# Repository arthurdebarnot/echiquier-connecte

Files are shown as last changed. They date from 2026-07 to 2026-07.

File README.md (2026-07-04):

# Echiquier connecté

## Installation des packages

`conda env create -f environment-windows.yml`

Il est nécessaire d'avoir l'exécutable `stockfish-windows-x86-64-avx2.exe` dans un dossier nommé `stockfish` pour que le programme fonctionne. Ce fichier peut être téléchargé au lien suivant : [télécharger stockfish 18](https://github.com/official-stockfish/Stockfish/releases/latest/download/stockfish-windows-x86-64-avx2.zip) (décompressez le fichier et placez le fichier stockfish dans le même dossier que les autres fichiers Python)

## Utilité de chaque fichier

- [main.py](./main.py) : contient la boucle de jeu : à chaque étape, calcule si un coup a été joué
- [magnetboard.py](./magnetboard.py) : définit la classe MagnetBoard qui permet de contenir l'état des reed switches mais aussi d'autres informations complémentaires importantes à stocker d'un tick à l'autre comme par exemple le fait qu'un roque est en train d'être fait
- [chesswindow.py](./chesswindow.py) : définit la classe ChessWindow qui permet de stocker la GUI et notamment ses différents éléments pour ensuite pouvoir les mettre à jour au fil des ticks
- [board_logic.py](./board_logic.py) : gère la compréhension de ce qui se passe sur le magnetBoard, comprend lorsqu'un coup est joué en fonction des reeds switches qui sont activés ou désactivés
- [evaluation.py](./evaluation.py) : contient les fonctions permettant de demander à Stockfish d'évaluer un coup
- [stockfish_interface.py](./stockfish_interface.py) : programme permettant de faire l'interface avec Stockfish et d'intéragir avec l'engine.
- [reedswitches-leds.py](./reedswitches-leds.py) : programme tournant sur la Raspberry Pi permettant d'allumer en vert les cases avec une pièces dessus. Nécessite l'installation des packages de [environment-rpi.yml](./environment-rpi.yml).

## Fonctionnement du programme

### Cas de simulation sans le raspberry

Etant donné que nous n'avons pas eu accès aux capteurs nous avons beaucoup développé l'aspect simulation des inputs pour tester notre programme d'échecs.

Le fichier à exécuter est celui qui s'appelle [main.py](./main.py). Il est possible de modifier le FEN de départ. Une interface graphique s'ouvre et permet de visualiser la position des capteurs allumés, ainsi que la position des pièces enregistrée par l'ordinateur.

En cliquant sur les cases, on peut simuler l'allumage ou l'extinction d'un reed switch. Lorsque le programme détecte qu'un coup a été effectué (par exemple, soulèvement du pion en e2, puis posage sur pion en e4), il met à jour son échiquier interne et déplace la lettre du pion.

Le programme prend en charge le roque, la prise en passant, la promotion ainsi que les différentes façon de terminer la partie : échec et mat, pat, insuffisance de matériel, nulle par répétition, nulle par suite consécutive de 50 coups sans prise ni déplacement de pion.

#### Promotion

Lorsqu'un pion arrive sur la case de promotion, il faut le changer en une autre pièce. Pour indiquer quelle pièce on a choisi à l'ordinateur, nous avons décidé de demander au joueur de modifier l'état d'une case tampon.

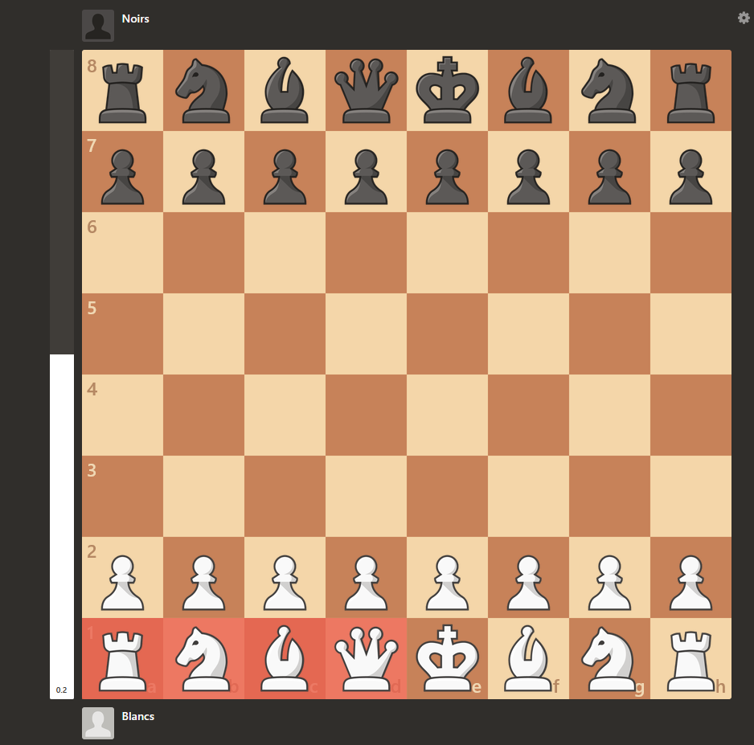
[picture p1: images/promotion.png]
image des cases tampons


Si une pièce est posée sur la case tampon, la pièce doit être soulevée puis reposée. Si aucune pièce n'est sur la case tampon, une pièce doit être posée puis reprise.

---

**ATTENTION**
Il faut bien penser que quand le pion est promu, il doit être remplacé par une autre pièce, et donc pour que l'ordinateur valide la promotion, la case du pion doit être désactivée puis réactivée pour simuler ce changement de pièce.

---

#### Choix du FEN de départ

Il est possible de changer la position de départ en le précisant à l'aide d'un FEN. Il est possible de trouver le FEN d'une position à l'aide de ce [lien](https://www.chess.com/analysis)

#### Evaluation par stockfish des coups

L'intérêt de cet échiquier connecté est de pouvoir évaluer chaque coup et donner du "feedback" en temps réel aux jouers. Ceci se fait à travers un algorithme d'échecs, Stockfish. À chaque coup, l'état du jeu (représenté par le FEN) est envoyé à Stockfish, qui évalue la situation et renvoie une valeur (qu'on passe ensuite dans la fonction $\mathrm{argsinh}$ pour donner plus de valeur à des modification d'évaluation proche de 0). En le comparant avec la situation d'avant, on peut ainsi juger la pertinence du coup.

## Partie électronique

### LED strip

Pour mieux communiquer des information importantes (coup illégal, "blunder", etc.) aux joueurs, une LED strip est mise sous l'échiquier et peut allumer chaque case de différentes couleurs (rouge, vert, orange, etc.). 

### Reed switch

Pour détecter la présence ou non d'une pièce, des reed switches sont mis sous chaque case et des aimants sont mis sous chaque pièce. Ainsi, lorsqu'une pièce est mise sur une case, le reed switch s'active et un courant circule. 

La lecture se fait grâce à [reedswitches-leds.py](./reedswitches-leds.py)

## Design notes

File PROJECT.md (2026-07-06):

## Echiquier Physique

### Pièces

Bien que de nombreux modèles de pièces d'échecs existent sur internet, nous avons préféré créer nos modèles nous même afin d'avoir un jeu adapter à la taille de nos cases et à celles des aimants que nous esperions recevoir. Du fait de l'absence des aimants, nous avons dû utiliser celle du projet IDS de cette année.

### Structure du plateau

Afin d'éviter que la LED d'une case n'en éclaire une autre, nous avons décidé de réaliser une grille coupant chaque cases de ses voisines. Seul un cercle bas dans le plateau permet aux cases de communiquer pour faire passer le ruban LED. 

La Grille a été réalisé grâce à la découpeuse laser, dont la précision permet un emboitement sans trop de jeu. Il y a un carré pour le bas. Chacune des 18 barres qui composent la grille sont tenus par 4 points à la plaque.

Le haut du plateau est une impression bicolore blanc-noir de 0.5mm, permettant de faire passer la lumière des LEDS. L'utilisation de PETG translucide pour mieux faire passer la lumière a été écarté sous les conseils de Némo.

### Capteurs

En l'absence de capteurs reçus, nous avons récupéré le montage du trimestre IDS de cette année. Nous n'avons donc pas pu réellement modifier cette structure et avons donc plutôt adapter le reste du plateau à celle-ci. 

ll aurait fallut faire usage d'un multiplexeur pour permettre de sonder toutes les cases malgré le nombre d'inputs limité du Raspberry Pi. En l'absence de celui-ci, nous n'avons accès qu'à 48 cases (8 colonnes et seulement 6 lignes). La strucutre récupéré a posé pas mal de problèmes (capteurs cassés, nécessité de resouder plusieurs connexions, etc.).

## Partie informatique

### Mission principale

Nous avons choisi d'utiliser le package python `chess.py` pour gérer ce qui révèle de la logique du jeu d'échecs en lui-même : légalité des coups, possibilité de réaliser une roque, etc. Notre défi était de donner, à partir des données des capteurs, les bonnes informations à `chess.py`. 

En effet, les capteurs nous indiquent seulement si il y a ou non une pièce sur une certaine case, mais n'en disent rien sur la nature de la pièce (que ce soit son rang ou son couleur). Il fallait ainsi construire une logique qui permet de passer de la "magnet-board" (grille de 1 et des 0 indiquant la présence ou non d'une pièce) à des coups compréhensibles par `chess.py`.

### Organisation du code

On a d'abord fait un prototype de code pour commencer réflechir à la structure du code. Cependant, il est vite devenu incompréhensible, et il fallait qu'on refasse tout de scratch pour avoir une architecture cohérente et robuste.

### Difficultés recontrées

Avoir une architecture de code cohérente et lisible était plus dur que prévu, il fallait réflechir en avance de comment on voulait structurer la logique et les interactions entre les différentes parties du code. 

Par ailleurs, la gestion des coups illégaux était un peu délicat : en effet, si `chess.py` détecte un mauvais coup, il réfuse de l'enregistrer. Mais physiquement parlant, la pièce a quand-même été déplacée, et il faut qu'on "dise au code" qu'il est "légal" de rebouger la pièce pour la remettre dans son position initial.

Une grande défi à surmonter était la gestion de la roque : de la point de vue du "magnet-board", c'est une situation très bizarre, puisqu'il voit 2 pièces de la même couleur soulevées, ce qui est normalement illégal. Il faut alors réussir à bien détecter ce qui se passe et basculer sur une autre système de gestion pour bien comprendre et enregistrer ce qui se passe sur l'échiquier.

## Lien physique - informatique

Malheureusement, en raison des difficultés du côté physique avec les capteurs, on n'a pas pu connecter les deux parties de notre projet. Avec un peu plus de temps, et surtout le matériel nécessaire, on aurait aimé faire le lien et compléter le projet.

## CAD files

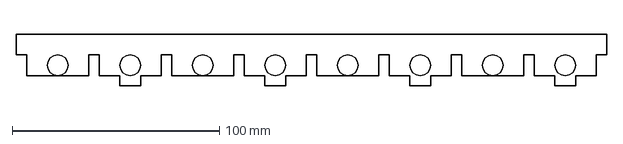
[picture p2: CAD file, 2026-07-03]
Echiquier physique/Fichiers Découpe-Laser/barre1.dxf
285.0 x 25.0 mm

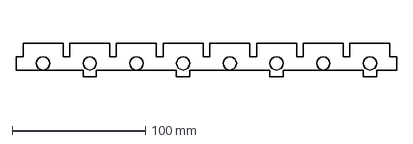
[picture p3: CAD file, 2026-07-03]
Echiquier physique/Fichiers Découpe-Laser/barre2.dxf
285.0 x 25.0 mm

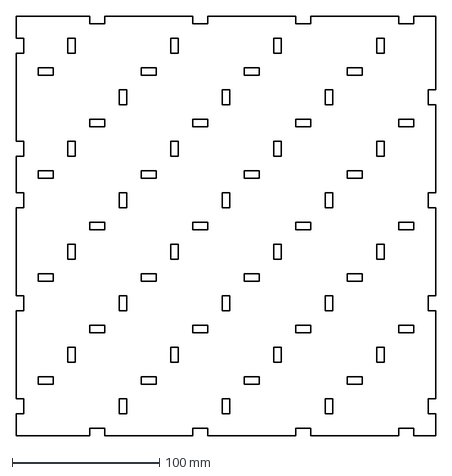
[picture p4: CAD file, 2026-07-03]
Echiquier physique/Fichiers Découpe-Laser/chees_bas.dxf
285.0 x 285.0 mm

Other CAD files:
Echiquier physique/Modèles 3D/barre-échecs.f3d
Echiquier physique/Modèles 3D/cavalier.f3d
Echiquier physique/Modèles 3D/echiquier bas.f3d
Echiquier physique/Modèles 3D/fou.f3d
Echiquier physique/Modèles 3D/pion.f3d
Echiquier physique/Modèles 3D/roi.f3d
Echiquier physique/Modèles 3D/échiquier.f3z

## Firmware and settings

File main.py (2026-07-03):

import chess
from board_logic import gameTick
from magnetboard import MagnetBoard
import evaluation as evaluation
from chesswindow import ChessWindow

fen = chess.STARTING_FEN # sélection du fen de la position de départ
prev_fen = fen # stocke le FEN de la dernière position

chessBoard = chess.Board(fen) # plateau d'échec de l'ordinateur
magnetBoard = MagnetBoard(chessBoard) # plateau magnétique se mettant à jour en fonction des reed switches
chessWindow = ChessWindow(magnetBoard, chessBoard) # fenêtre graphique

prev_value = evaluation.evaluate(chessBoard.fen()) # évaluation de la dernière position


while True:
    gameTick(magnetBoard, chessBoard, chessWindow) # collecte les nouveaux états des reed switches et met à jour le magnetBoard et le chessBoard si besoin. Mets aussi à jour la gui

    # Vérification des conditions de fin de partie

    if chessBoard.is_checkmate():
        print("Fin de partie par échec et mat !")
        break
    if chessBoard.is_stalemate():
        print("Fin de partie par pat !")
        break
    if chessBoard.is_insufficient_material():
        print("Fin de partie par manque de matériel !")
        break
    if chessBoard.can_claim_draw():
        print("La nulle peut être réclamée !")
        break

    prev_fen, prev_value = evaluation.judge_move(chessBoard, prev_fen, prev_value) # mise à jour de la dernière évaluation et du dernier fen

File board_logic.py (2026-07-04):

## Code pour gérer la plateau de jeu: quelles pièces sont où, etc.
import numpy as np
import chess
import time
from magnetboard import MagnetBoard
from chesswindow import ChessWindow

# Game Loop
def gameTick(magnetBoard: MagnetBoard, chessBoard: chess.Board, chessWindow: ChessWindow):
    """Effectue toutes les actions pour détecter de potentiels nouveaux coups joués"""

    previous_magnetBoard = magnetBoard.board.copy() # copie du dernier état du magnetBoard

    magnetBoard.update(chessBoard, chessWindow) # collecte de l'état des reed switches

    move = None

    if magnetBoard.is_invalid: # cas où un coup invalide aurait été joué et qu'on attend que le plateau revienne dans la dernière position valide
        if np.array_equal(magnetBoard.board, magnetBoard.last_valid_board):
            if magnetBoard.validation_start_time < 0:
                magnetBoard.validation_start_time = time.time() # premier instant où le plateau est revenu dans une position valide
            elif time.time() - magnetBoard.validation_start_time >= 2: # si le plateau est dans la dernière posiiton valide depuis plus de 2 secondes, on reprend le fonctionnement normal
                magnetBoard.is_invalid = False
                magnetBoard.validation_start_time = -1
                magnetBoard.friendly_piece_up_square = None
                magnetBoard.opponent_piece_up_square = None
                magnetBoard.is_castling = None
                magnetBoard.castling_rook_squares = None
                magnetBoard.is_promoting = False
                magnetBoard.promoting_piece_type = None
                magnetBoard.is_promotion_done = False
                magnetBoard.current_move = None
                print("La partie peut continuer !")
        else: # si on n'est pas dans la dernière position valide, on attend
            magnetBoard.validation_start_time = -1
        return

    if np.array_equal(magnetBoard.board, previous_magnetBoard): # s'il n'y a eu aucun changement sur le plateau on ne fait rien
        return
    
    # on détecte les différences entre l'état précédents et le nouvel état

    difference_magnetBoard = magnetBoard.board - previous_magnetBoard 
    difference_magnetBoard_nonzero = difference_magnetBoard.nonzero()

    if len(difference_magnetBoard_nonzero[0]) > 1: # si il y a plus d'une modification, on ne peut rien interpréter donc on rentre dans un cas invalide
        print("[INVALIDE] plusieurs pièces bougées en même temps")
        magnetBoard.is_invalid = True
        return
    
    modified_square = chess.square(difference_magnetBoard_nonzero[1][0], difference_magnetBoard_nonzero[0][0]) # on stocke la case modifiée

    if magnetBoard.is_promoting: # si une promotion est en cours
        tampon_squares = [chess.square(i, 7*(1 - chessBoard.turn)) for i in range(4)]

        if modified_square == magnetBoard.current_move.to_square: # la case du pion promu est en jeu
            if difference_magnetBoard[difference_magnetBoard_nonzero][0] == -1: # pion soulevé
                return
            else: # pion posé
                magnetBoard.is_promotion_done = True # variable qui retient si le pion a bien été promu en une autre pièce sur l'échiquier physique
        elif modified_square not in tampon_squares: # on touche à une case random pendant la promotion
            print("[INVALIDE] Tu ne peux pas modifier l'état d'une case random pendant la promotion")
            magnetBoard.is_invalid = True
            return
        else: # on modifie l'état d'une des 4 cases tampon
            if magnetBoard.friendly_piece_up_square is not None and magnetBoard.friendly_piece_up_square != modified_square:
                print("[INVALIDE] Tu as déjà touché une autre pièce")
                magnetBoard.is_invalid = True
                return

            magnetBoard.friendly_piece_up_square = modified_square # on stocke la case tampon modifiée, aucun rapport avec friendly ou que la pièce soit soulevée ou posée
            
            if magnetBoard.board[difference_magnetBoard_nonzero] != magnetBoard.last_valid_board[difference_magnetBoard_nonzero]: # tant qu'on n'est pas revenu dans l'état initial de la case tampon, on ne fait rien
                return
            
            # on est revenu à un état normal

            magnetBoard.promoting_piece_type = chess.Board(chess.STARTING_FEN).piece_at(modified_square).piece_type # on regarde alors la pièce qui correspond à la case tampon

        if not magnetBoard.is_promotion_done or magnetBoard.promoting_piece_type is None: # si la promotion n'est pas effectuée ou que la pièce n'est pas sélectionnée, on ne fait rien
            return
            
        magnetBoard.current_move.promotion = magnetBoard.promoting_piece_type # on modifie le coup à applique pour indiquer que c'est une promotion en la pièce choisie

        chessBoard.push(magnetBoard.current_move) # on ajoute le coup au chessBoard
        magnetBoard.last_valid_board = magnetBoard.board.copy() # on modifie le dernier magnetBoard valide

        magnetBoard.friendly_piece_up_square = None
        magnetBoard.is_promoting = False
        magnetBoard.is_promotion_done = False
        magnetBoard.current_move = None
        magnetBoard.promoting_piece_type = None
        return
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

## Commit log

2026-06-29 Added script for managing the board
2026-06-29 création fichier test simulation d'entrées du raspberry
2026-06-29 updated board logic
2026-06-29 updated board logic: end of day 29/06/26
2026-06-30 Stockfish lancé une seule fois pour toute la partie
2026-06-30 fixed bugs and added interface
    [board_logic.py]
2026-06-30 Added main script and changed architecture of board_logic.py
2026-06-30 evaluation stockfish and fix board_logic bug
    [board_logic.py, main.py]
2026-06-30 board logic
2026-07-02 Fin de partie
2026-07-02 bug fixed in evaluation.py
    [evaluation.py, main.py]
2026-07-03 ajustement pour la prise en passant
2026-07-03 annotation de main et board_logic
2026-07-03 Gestion des Reed-switches et des LEDs
2026-07-03 Ajout fichiers impression 3D et découpe laser
    [barre-échecs.f3d, barre1.dxf, barre2.dxf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]
2026-07-04 bug fixed : l'évaluation se faisait en continu, modification du message d'erreur lors d'une position invalide pour le rendre plus lisible
    [board_logic.py, evaluation.py]
2026-07-04 Début PROJECT.md et écriture correct de requirements.txt
